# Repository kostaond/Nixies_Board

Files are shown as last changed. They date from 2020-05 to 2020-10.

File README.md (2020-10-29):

# Nixies_Board
This repository stores Nixie Clock PCB board and schematics created in Eagle. It also contains drawings and 3D model of the metal box. 

The design goal is to create a Nixie clocks driven by low-cost ARM processor with simple serial interface which is used for clock power down scenario remedy and for time synchronization. The actual solution for the time synchronization is up to the user and can be realized by e.g. Bluetooth or Wifi modules like Wemos D1.

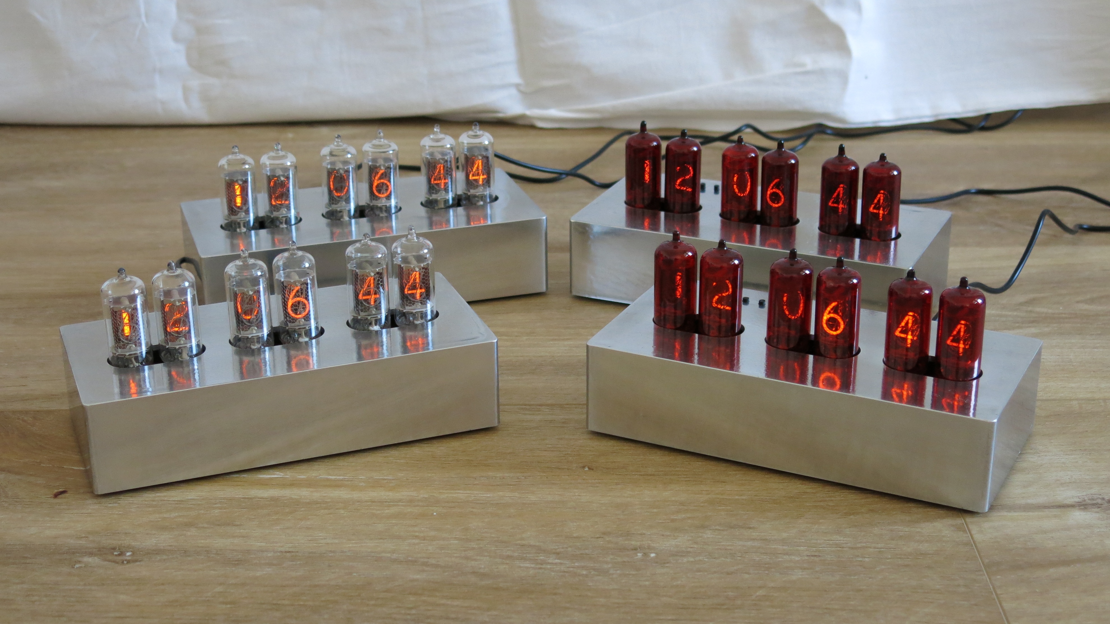
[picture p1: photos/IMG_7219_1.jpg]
Image of Clock


Notes:
 - Power supply is based on https://threeneurons.wordpress.com/nixie-power-supply/
 - High voltage part of the design can be disabled by disconnecting JP2. This is handy for software debugging from the safety perspective.
 - I saw that a lot of people had an issue with ghosting when multiplexing the nixies. I was not an exception. The solution is to connect all cathodes to pre-bias voltage of 100V via e.g. 220K rezistors (check the schematics for more details).  Refer to Section "OFF CATHODE CHARACTERISTICS" at http://www.zapro.dk/public/PDF/nixie/N101.pdf to find magic behind.

Two revisions exist in this repository – REV1 and REV2 (see tags). 
* The REV1 is the very first prototype where the wrong BCD decoder was used (74HC42 with active low output while BCD decoder with active high should have been used). This could be partially resolved by resoldering with 4028, external wiring and SW workaround. However DO NOT use this version!
* The REV2 fixes the issue with the BCD decoder, resolves ghosting and adds footprint preparation for Wemos D1 Wifi modul.

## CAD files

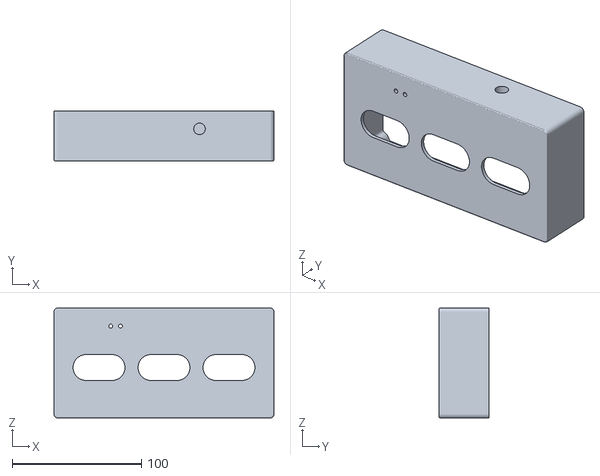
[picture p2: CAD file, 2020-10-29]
case/nixie_box.stl
170.0 x 39.0 x 85.0

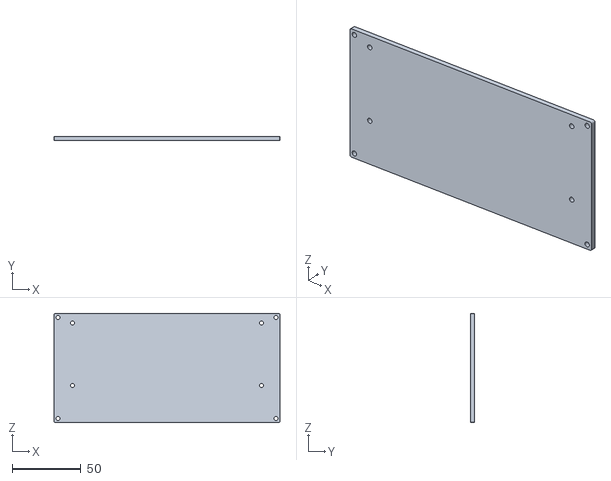
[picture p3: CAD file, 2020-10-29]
case/bottom.stl
164.5 x 3.00 x 79.5

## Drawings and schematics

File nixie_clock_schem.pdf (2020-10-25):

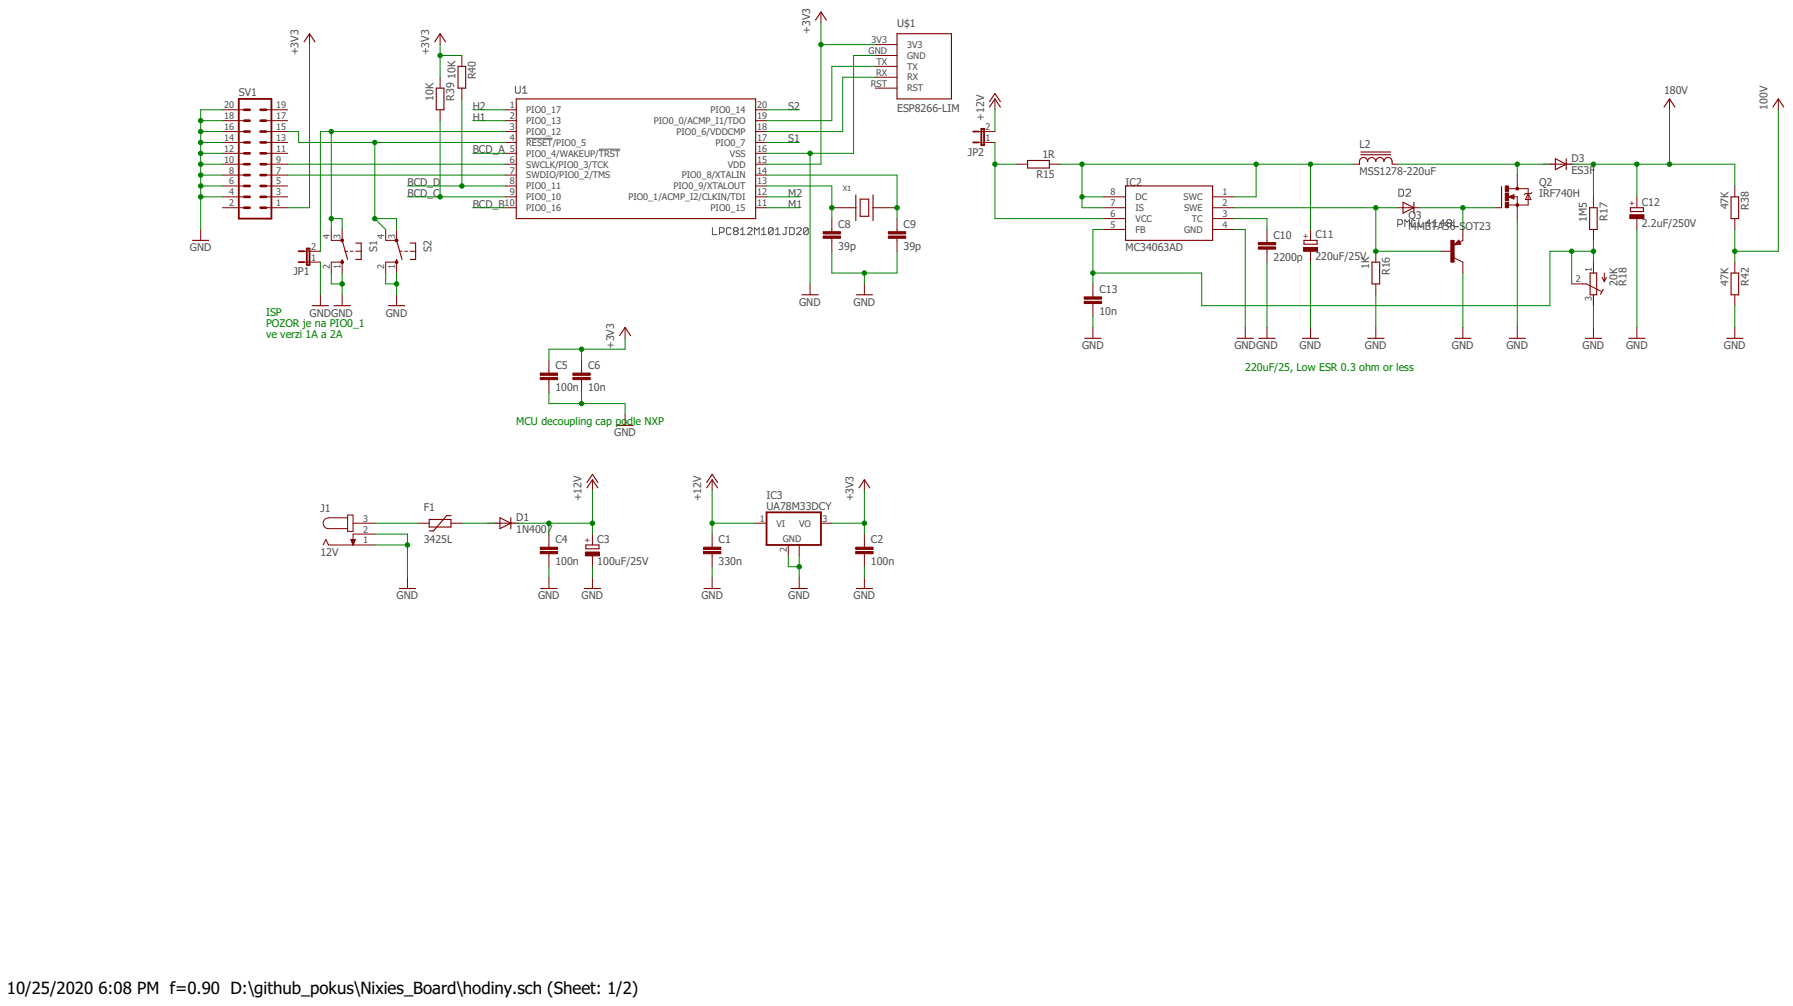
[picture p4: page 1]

220uF/25, Low ESR 0.3 ohm or less

MCU decoupling cap podle NXP

10/25/2020 6:08 PM f=0.90 D:\github_pokus\Nixies_Board\hodiny.sch (Sheet: 1/2)

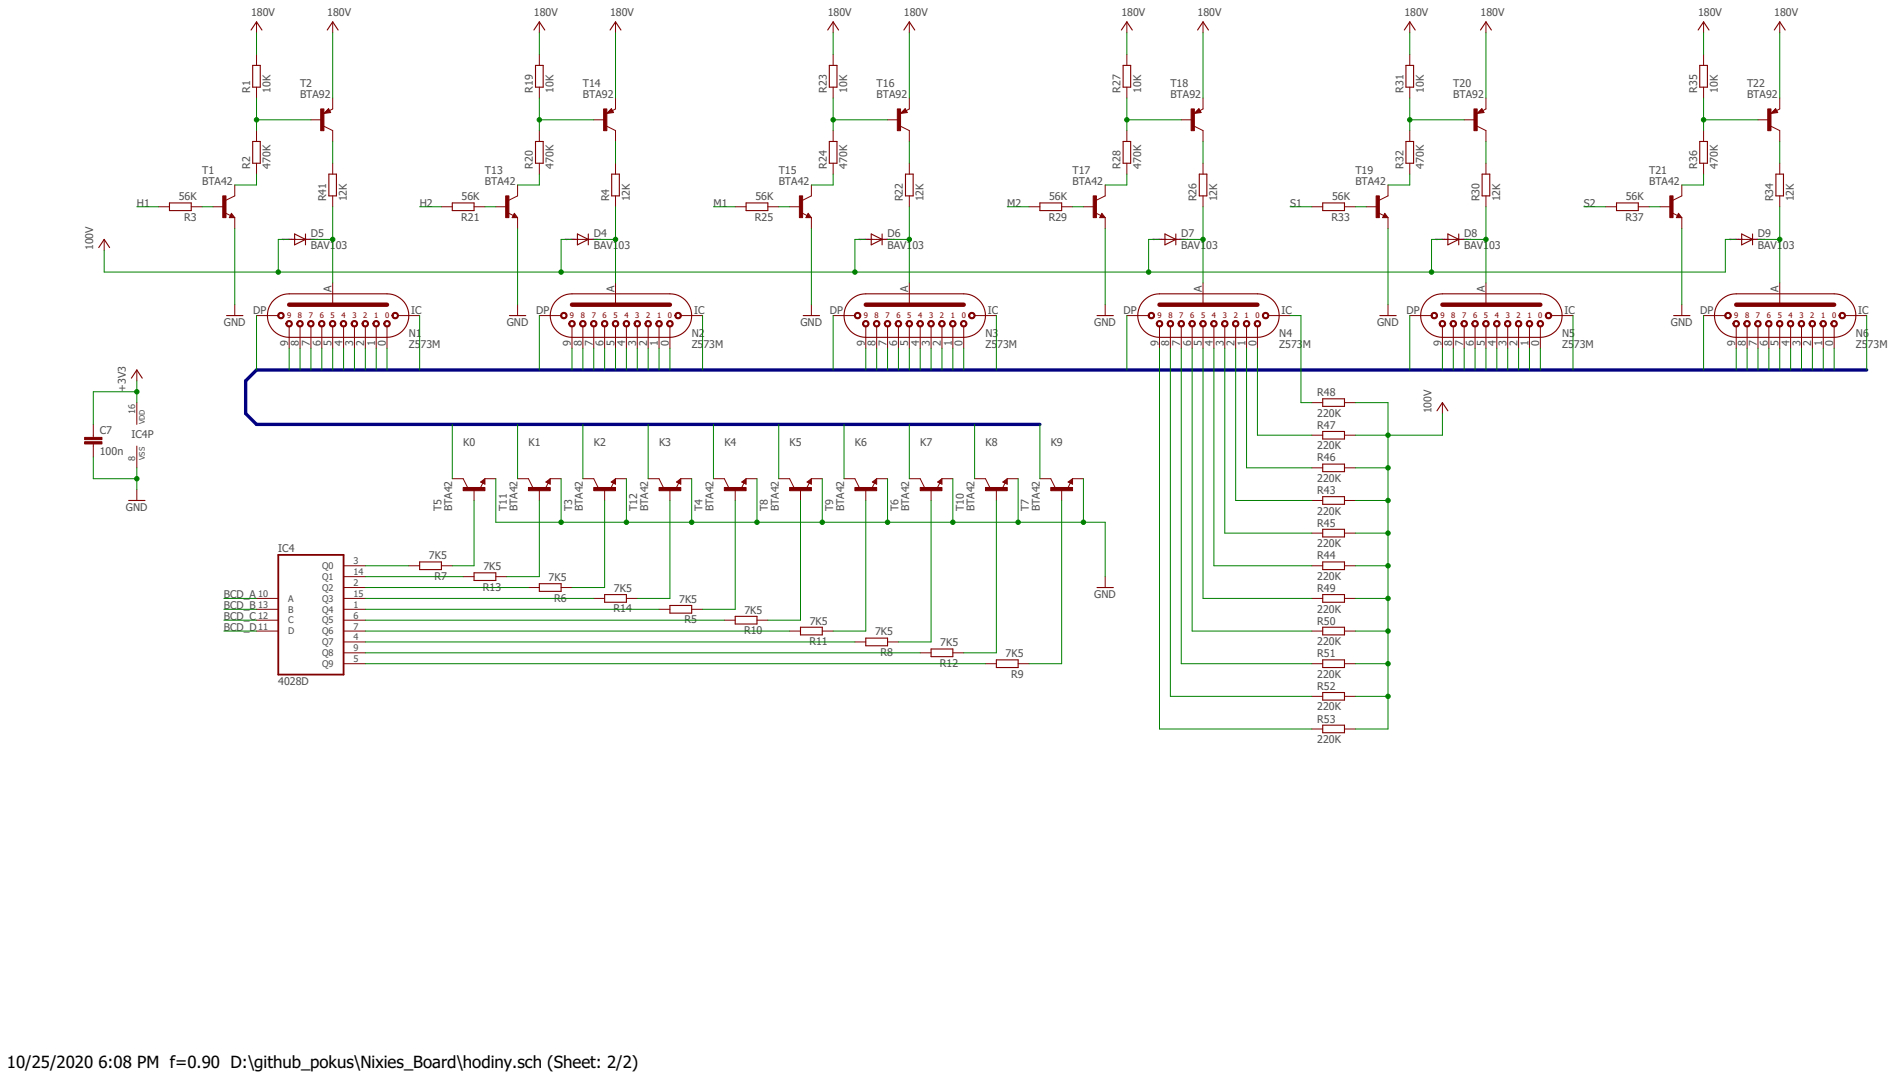
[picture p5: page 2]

10/25/2020 6:08 PM f=0.90 D:\github_pokus\Nixies_Board\hodiny.sch (Sheet: 2/2)

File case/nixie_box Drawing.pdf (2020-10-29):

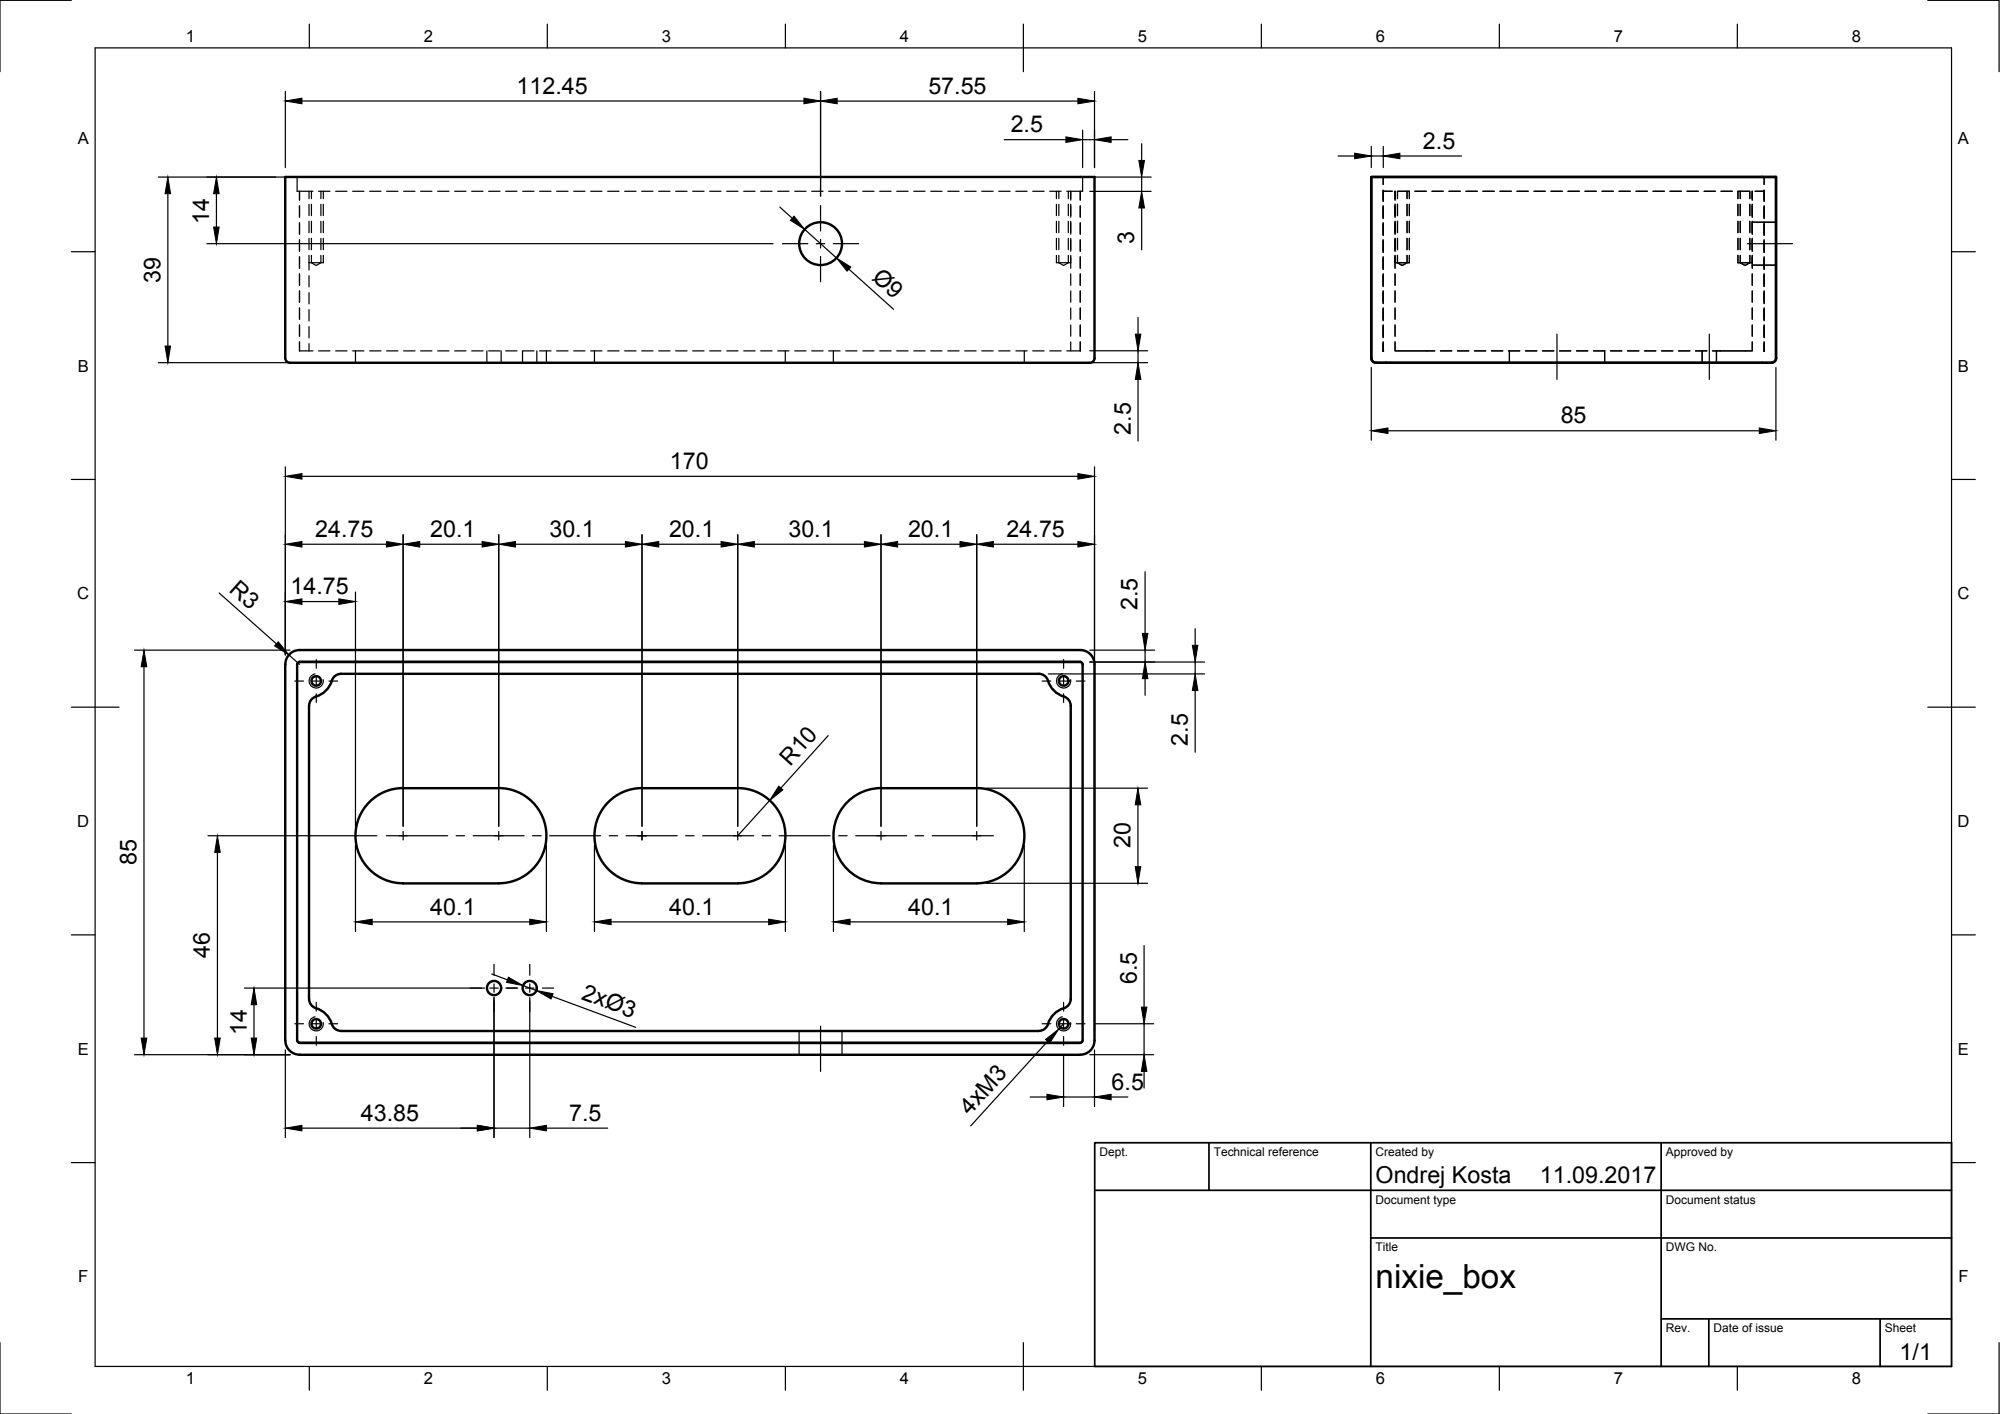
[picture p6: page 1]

Dept. | Technical reference | Created by Ondrej Kosta 11.09.2017 | Approved by

Document type | Document status

Title nixie_box | DWG No.

Rev. | Date of issue | Sheet 1/1

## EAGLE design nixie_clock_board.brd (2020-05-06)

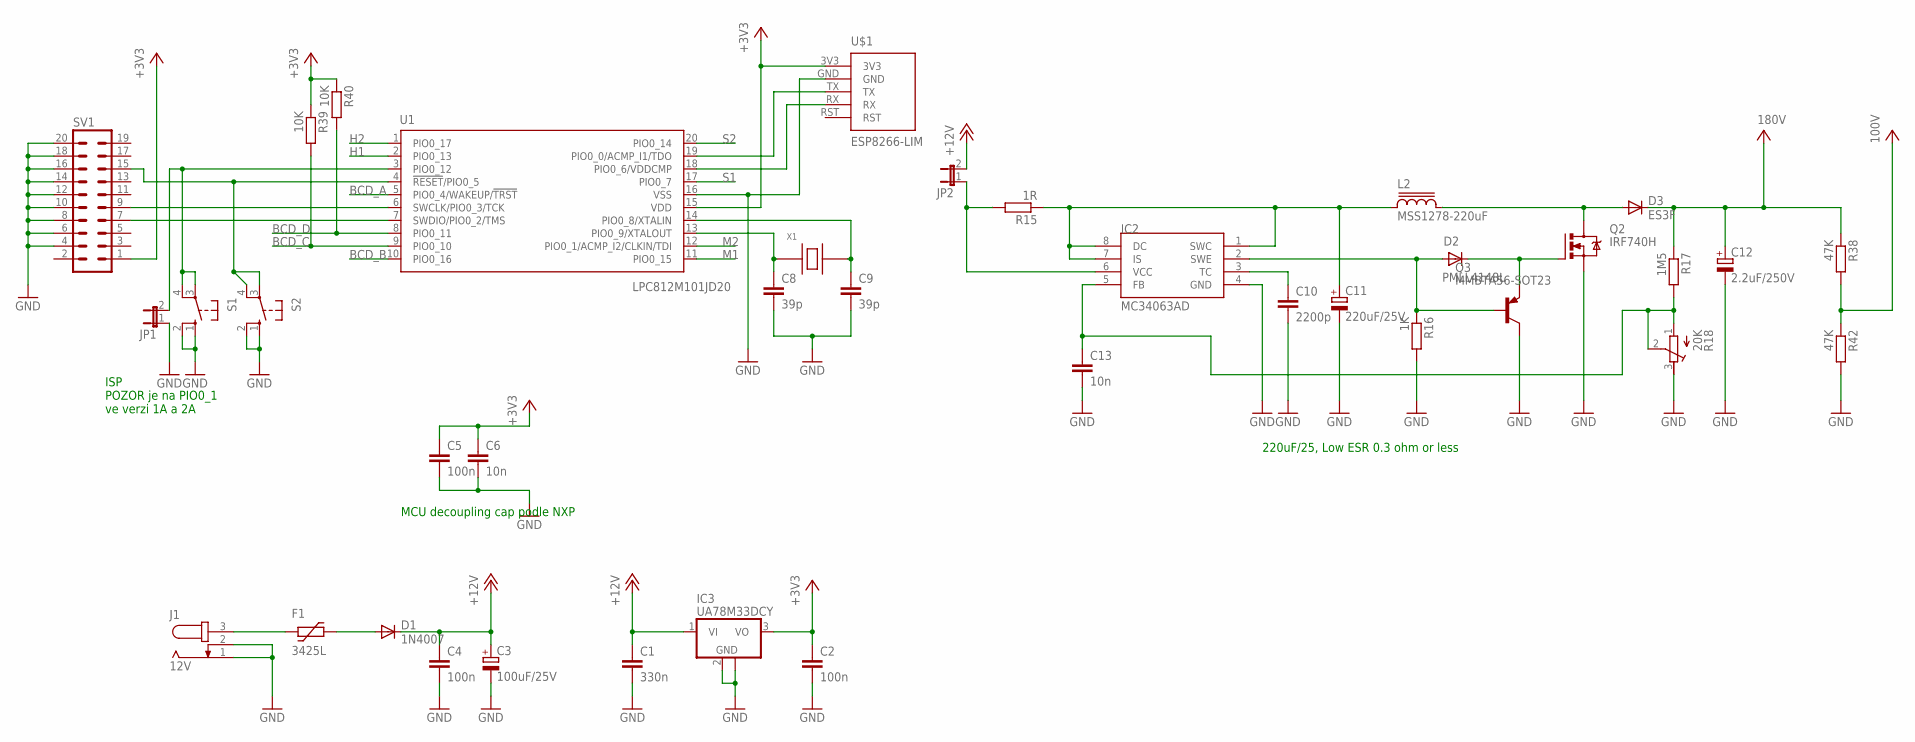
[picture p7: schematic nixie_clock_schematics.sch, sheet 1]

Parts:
C1: 330n; C1206
C2, C4, C5: 100n; C1206
C3: 100uF/25V; 153CLV-0605
C6, C13: 10n; C1206
C8, C9: 39p; C0805
C10: 2200p; C1206
C11: 220uF/25V; 153CLV-0605
C12: 2.2uF/250V; E2,5-6
D1: 1N4007; MELF-MLL41
D2: PMLL4148L; SOD80C
D3: ES3F; SMC
F1: 3425L
IC2: MC34063AD; SOIC8
IC3: UA78M33DCY; SOT223
J1: 12V; SPC4077
JP1, JP2: JP1E; JP1
L2: MSS1278-220uF; MSS1278
Q2: IRF740H; TO220BH
Q3: MMBTA56-SOT23; SOT23
R15: 1R; R1206
R16: 1K; R1206
R17: 1M5; R1206
R18: 20K; RTRIM4G/J
R38, R42: 47K; 0207/7
R39, R40: 10K; R1206
S1, S2: 10-XX; B3F-10XX
SV1: ML20
U1: LPC812M101JD20; SOT163-1
U$1: ESP8266-LIM
X1: SMCE-5032; IQG5032B

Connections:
100V: R38.2, R42.1; also elsewhere on the board
180V: C12.+, D3.C, R17.1, R38.1; also elsewhere on the board
+3V3: C2.1, C5.1, C6.1, IC3.3 (VO), R39.1, R40.1, SV1.1, U1.15 (VDD), U$1.3V3; also elsewhere on the board
+12V: C1.1, C3.+, C4.1, D1.C, IC3.1 (VI), JP2.2
BCD_A: U1.5 (PIO0_4/WAKEUP/!TRST!); also elsewhere on the board
BCD_B: U1.10 (PIO0_16); also elsewhere on the board
BCD_C: R39.2, U1.9 (PIO0_10); also elsewhere on the board
BCD_D: R40.2, U1.8 (PIO0_11); also elsewhere on the board
GND: C1.2, C2.2, C3.-, C4.2, C5.2, C6.2, C8.2, C9.2, C10.2, C11.-, C12.-, C13.2, IC2.4 (GND), IC3.2 (GND), IC3.4 (GND), J1.1, J1.2, JP1.1, Q2.S, Q3.3 (C), R16.2, R18.3 (E), R42.2, S1.1 (S), S1.2 (S1), S2.1 (S), S2.2 (S1), SV1.4, SV1.6, SV1.8, SV1.10, SV1.12, SV1.14, SV1.16, SV1.18, SV1.20, U1.16 (VSS), U$1.GND; also elsewhere on the board
H1: U1.2 (PIO0_13); also elsewhere on the board
H2: U1.1 (PIO0_17); also elsewhere on the board
M1: U1.11 (PIO0_15); also elsewhere on the board
M2: U1.12 (PIO0_1/ACMP_I2/CLKIN/TDI); also elsewhere on the board
unnamed: F1.P$1 (1), J1.3
unnamed: D1.A, F1.P$2 (2)
unnamed: S2.3, S2.4 (P1), SV1.15, U1.4 (!RESET!/PIO0_5)
unnamed: JP1.2, S1.3, S1.4 (P1), U1.3 (PIO0_12)
unnamed: SV1.9, U1.6 (SWCLK/PIO0_3/TCK)
unnamed: SV1.7, U1.7 (SWDIO/PIO0_2/TMS)
unnamed: C9.1, U1.14 (PIO0_8/XTALIN), X1.3 (PIN2)
unnamed: C8.1, U1.13 (PIO0_9/XTALOUT), X1.1 (PIN1)
unnamed: U1.18 (PIO0_6/VDDCMP), U$1.RX
unnamed: C11.+, IC2.1 (SWC), IC2.7 (IS), IC2.8 (DC), L2.1, R15.1
unnamed: C10.1, IC2.3 (TC)
unnamed: D2.1 (K), Q2.G, Q3.2 (E)
unnamed: D3.A, L2.2, Q2.D
unnamed: D2.2 (A), IC2.2 (SWE), Q3.1 (B), R16.1
unnamed: IC2.6 (VCC), JP2.1, R15.2
unnamed: C13.1, IC2.5 (FB), R17.2, R18.1 (A), R18.2 (S)
unnamed: U1.19 (PIO0_0/ACMP_I1/TDO), U$1.TX
S1: U1.17 (PIO0_7); also elsewhere on the board
S2: U1.20 (PIO0_14); also elsewhere on the board

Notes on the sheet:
MCU decoupling cap podle NXP
ISP POZOR je na PIO0_1 ve verzi 1A a 2A
220uF/25, Low ESR 0.3 ohm or less

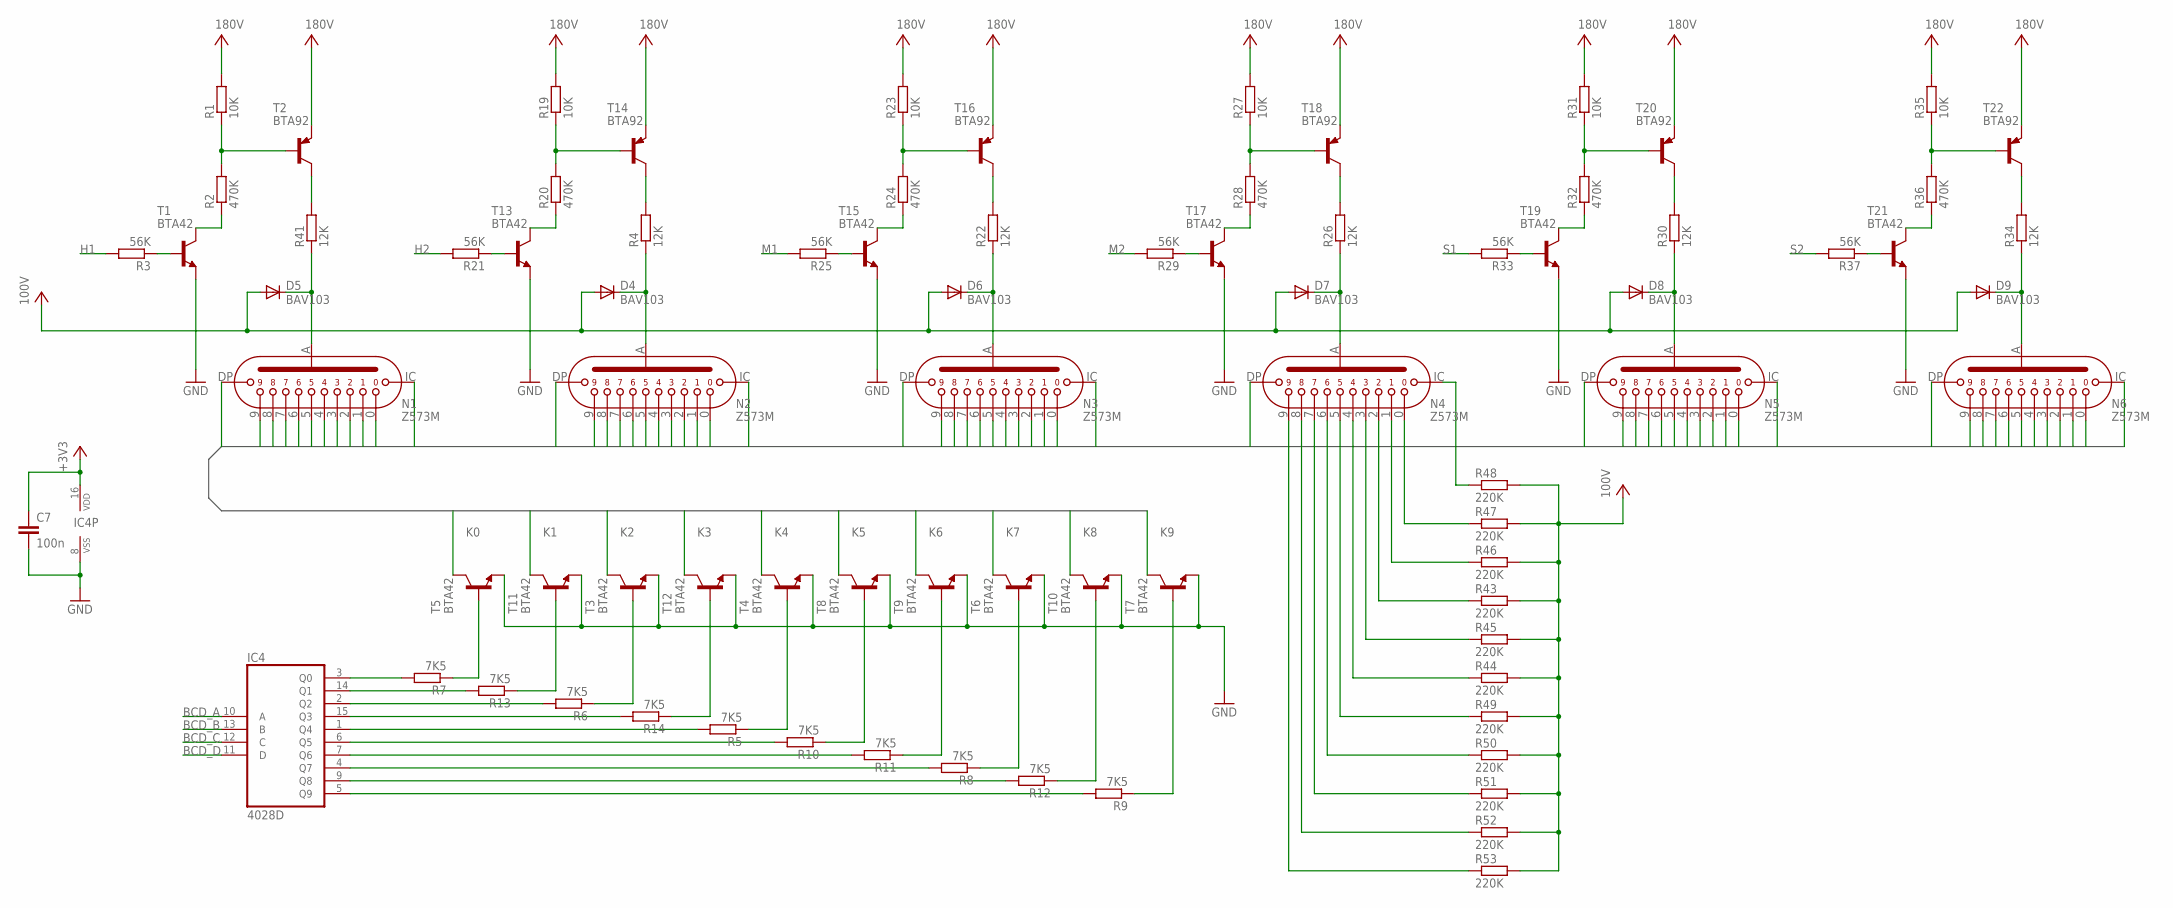
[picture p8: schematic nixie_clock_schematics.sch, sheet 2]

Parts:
C7: 100n; C1206
D4, D5, D6, D7, D8, D9: BAV103; MINIMELF
IC4: 4028D; SO16
N1, N2, N3, N4, N5, N6: Z573M; Z570M
R1, R19, R23, R27, R31, R35: 10K; R1206
R2, R20, R24, R28, R32, R36: 470K; R1206
R3, R21, R25, R29, R33, R37: 56K; R1206
R4, R22, R26, R30, R34, R41: 12K; 0207/7
R5, R6, R7, R8, R9, R10, R11, R12, R13, R14: 7K5; R1206
R43, R44, R45, R46, R47, R48, R49, R50, R51, R52, R53: 220K; R1206
T1, T3, T4, T5, T6, T7, T8, T9, T10, T11, T12, T13, T15, T17, T19, T21: BTA42; SOT23-BEC
T2, T14, T16, T18, T20, T22: BTA92; SOT23-BEC

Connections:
100V: D4.A, D5.A, D6.A, D7.A, D8.A, D9.A, R43.2, R44.2, R45.2, R46.2, R47.2, R48.2, R49.2, R50.2, R51.2, R52.2, R53.2; also elsewhere on the board
180V: R1.2, R19.2, R23.2, R27.2, R31.2, R35.2, T2.E, T14.E, T16.E, T18.E, T20.E, T22.E; also elsewhere on the board
+3V3: C7.1, IC4.16 (VDD); also elsewhere on the board
BCD_A: IC4.10 (A); also elsewhere on the board
BCD_B: IC4.13 (B); also elsewhere on the board
BCD_C: IC4.12 (C); also elsewhere on the board
BCD_D: IC4.11 (D); also elsewhere on the board
GND: C7.2, IC4.8 (VSS), T1.E, T3.E, T4.E, T5.E, T6.E, T7.E, T8.E, T9.E, T10.E, T11.E, T12.E, T13.E, T15.E, T17.E, T19.E, T21.E; also elsewhere on the board
H1: R3.2; also elsewhere on the board
H2: R21.2; also elsewhere on the board
K0: N1.12 (0), N2.12 (0), N3.12 (0), N4.12 (0), N5.12 (0), N6.12 (0), R47.1, T5.C
K1: N1.1, N2.1, N3.1, N4.1, N5.1, N6.1, R46.1, T11.C
K2: N1.2, N2.2, N3.2, N4.2, N5.2, N6.2, R43.1, T3.C
K3: N1.3, N2.3, N3.3, N4.3, N5.3, N6.3, R45.1, T12.C
K4: N1.5 (4), N2.5 (4), N3.5 (4), N4.5 (4), N5.5 (4), N6.5 (4), R44.1, T4.C
K5: N1.6 (5), N2.6 (5), N3.6 (5), N4.6 (5), N5.6 (5), N6.6 (5), R49.1, T8.C
K6: N1.7 (6), N2.7 (6), N3.7 (6), N4.7 (6), N5.7 (6), N6.7 (6), R50.1, T9.C
K7: N1.8 (7), N2.8 (7), N3.8 (7), N4.8 (7), N5.8 (7), N6.8 (7), R51.1, T6.C
K8: N1.9 (8), N2.9 (8), N3.9 (8), N4.9 (8), N5.9 (8), N6.9 (8), R52.1, T10.C
K9: N1.11 (9), N2.11 (9), N3.11 (9), N4.11 (9), N5.11 (9), N6.11 (9), R53.1, T7.C
K10: N1.4 (IC), N1.10 (DP), N2.4 (IC), N2.10 (DP), N3.4 (IC), N3.10 (DP), N4.4 (IC), N4.10 (DP), N5.4 (IC), N5.10 (DP), N6.4 (IC), N6.10 (DP), R48.1
M1: R25.2; also elsewhere on the board
M2: R29.2; also elsewhere on the board
unnamed: R3.1, T1.B
unnamed: R2.1, T1.C
unnamed: R1.1, R2.2, T2.B
unnamed: R21.1, T13.B
unnamed: R41.2, T2.C
unnamed: IC4.1 (Q4), R5.2
unnamed: D5.C, N1.13 (A), R41.1
unnamed: IC4.2 (Q2), R6.2
unnamed: IC4.3 (Q0), R7.2
unnamed: IC4.4 (Q7), R8.2
unnamed: IC4.5 (Q9), R9.2
unnamed: IC4.6 (Q5), R10.2
unnamed: IC4.7 (Q6), R11.2
unnamed: IC4.9 (Q8), R12.2
unnamed: IC4.14 (Q1), R13.2
unnamed: IC4.15 (Q3), R14.2
unnamed: R5.1, T4.B
unnamed: R6.1, T3.B
unnamed: R7.1, T5.B
unnamed: R8.1, T6.B
unnamed: R10.1, T8.B
unnamed: R11.1, T9.B
unnamed: R12.1, T10.B
unnamed: R13.1, T11.B
unnamed: R14.1, T12.B
unnamed: R9.1, T7.B
unnamed: R20.1, T13.C
unnamed: R19.1, R20.2, T14.B
unnamed: R4.2, T14.C
unnamed: D4.C, N2.13 (A), R4.1
unnamed: R25.1, T15.B
unnamed: R24.1, T15.C
unnamed: R23.1, R24.2, T16.B
unnamed: R22.2, T16.C
unnamed: D6.C, N3.13 (A), R22.1
unnamed: R29.1, T17.B
unnamed: R28.1, T17.C
unnamed: R27.1, R28.2, T18.B
unnamed: R26.2, T18.C
unnamed: D7.C, N4.13 (A), R26.1
unnamed: R33.1, T19.B
unnamed: R32.1, T19.C
unnamed: R31.1, R32.2, T20.B
unnamed: R30.2, T20.C
unnamed: D8.C, N5.13 (A), R30.1
unnamed: R37.1, T21.B
unnamed: R36.1, T21.C
unnamed: R35.1, R36.2, T22.B
unnamed: R34.2, T22.C
unnamed: D9.C, N6.13 (A), R34.1
S1: R33.2; also elsewhere on the board
S2: R37.2; also elsewhere on the board

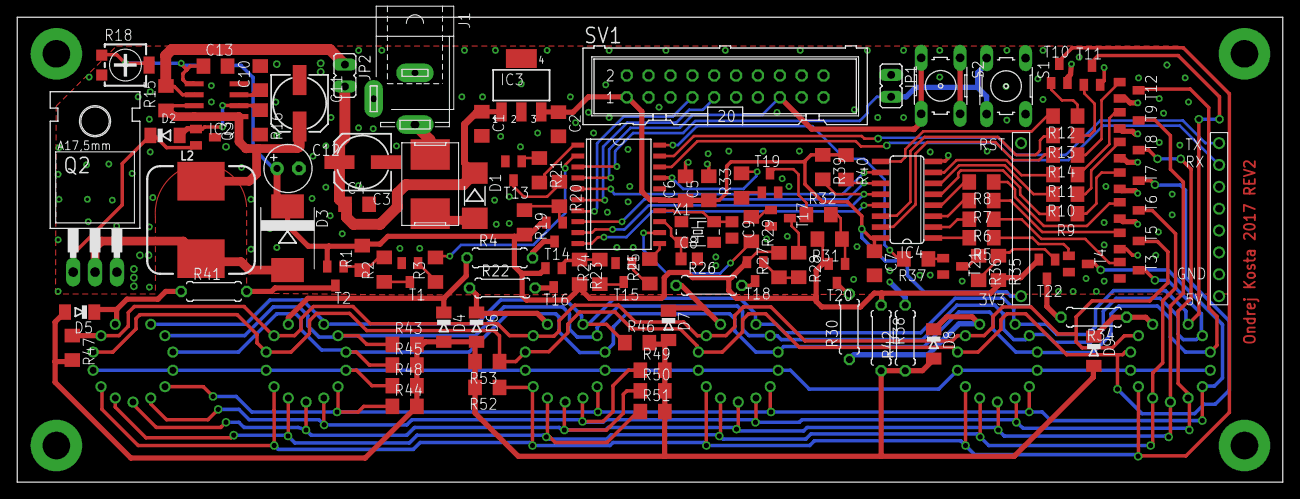
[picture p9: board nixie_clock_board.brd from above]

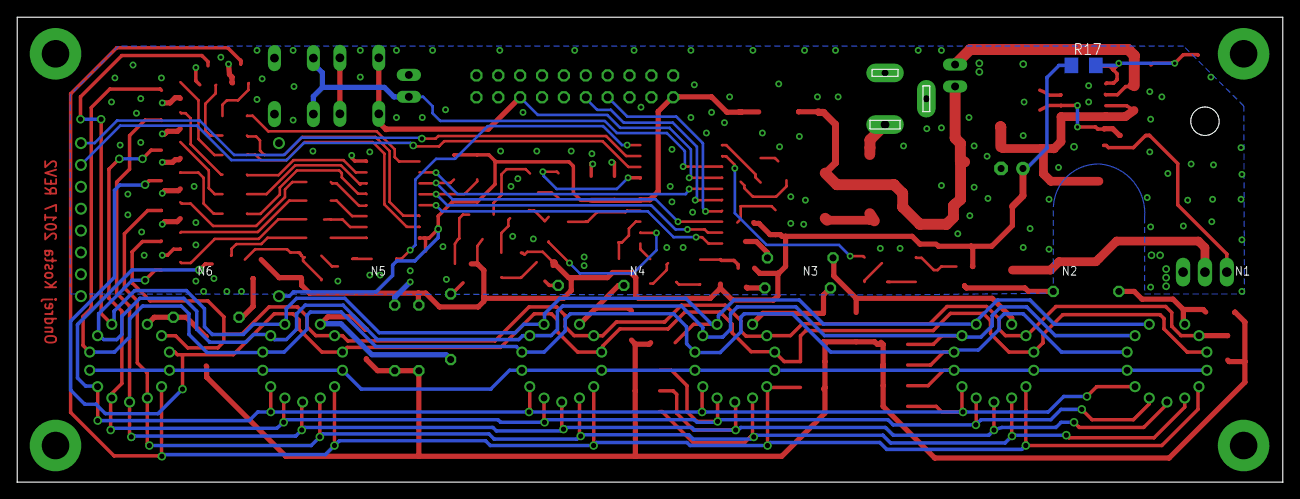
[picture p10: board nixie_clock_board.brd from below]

Board: 2 copper layers, 147.0 x 54.0 mm, 119 parts (7 on the bottom side), 93 nets.

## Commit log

2020-05-06 REV 1
    [hodiny.brd, hodiny.sch]
2020-05-06 REV2 - Red Board
    [hodiny.brd, hodiny.sch]
2020-10-25 - renamed to English - PDF output
    [nixie_clock_board.brd, nixie_clock_schematics.sch]
2020-10-29 Nixie Box
    Nixie box drawing, models and photo added.
    [bottom.stl, nixie_box.stl]

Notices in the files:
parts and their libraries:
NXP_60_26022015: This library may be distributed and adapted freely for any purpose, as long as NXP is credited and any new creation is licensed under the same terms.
